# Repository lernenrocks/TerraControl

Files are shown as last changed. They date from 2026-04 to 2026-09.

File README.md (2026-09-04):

# TerraControl

> **🚧 Currently being redesigned.** Sensor and relay handling are being
> reworked onto a shared class hierarchy (NVI pattern), and the project
> went headless (no display, no SD card) in favor of a web GUI. This
> README does not reflect the current architecture yet — it will be
> updated once the redesign settles.

*Smart terrarium control for those who don't want their setup 
to stop working the day some company decides to shut down their 
servers — and for those who need more than one or two plugs. 
A work in progress measured in years, not sprints, with a parts budget that long surpassed the 
price of the off-the-shelf box, not counting the ones that 
released their magic smoke. And if this accidentally turns out 
to be a solid foundation for a home automation system — well, 
that was definitely not the plan.*

## How It Works

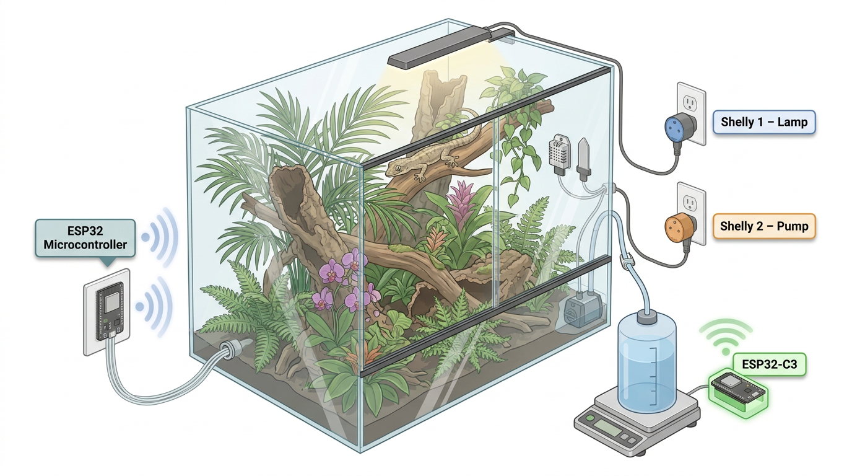
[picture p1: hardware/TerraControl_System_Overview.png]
TerraControl System Overview


> **Note:** The system overview image is AI-generated (FigureLabs).
> It contains minor technical inaccuracies that survived several
> rounds of prompt engineering before patience and token budget
> ran out simultaneously. It will be replaced by actual photos
> once the prototype is running. If you happen to have a free and
> freely usable image of a terrarium control setup — contributions
> are very welcome.
>
> **Not current** — this image predates the headless decision and
> the sensor/relay redesign; some details no longer match the actual
> architecture.

An ESP32 sits at the heart of the system as the **MainUnit**. It runs its own WiFi access point — Shelly smart plugs connect directly to the ESP32, not to your home router. This keeps all device communication local and independent of cloud services or internet connectivity.

Sensors measure conditions inside the terrarium (temperature, humidity, soil moisture). The MainUnit reads these values and switches the Shellys accordingly — controlling lighting, heating, irrigation, or anything else that plugs into a wall socket.

The ESP32 also connects to your home router as a client, exclusively for time synchronization and future remote access. If your router goes down, the Shellys and sensors remain fully operational.

**Shelly smart plugs** are identified by their MAC address, not by IP. The ESP32 assigns and tracks IPs automatically — no manual configuration required on the network side.

## Roadmap

- [x] Shelly Gen2/3 control — switch on/off, status monitoring, authenticated via SHA-256 Digest Auth
- [x] Soft-AP — ESP32 as primary access point; Shellys connect directly to ESP32, isolated from the home network
- [x] WiFiWorker — dedicated background task handling all network communication with Shellys (being split into RequestWorker + GuiWorker)
- [x] `SensorBase` (NVI pattern) — DHT22 temperature/humidity (4 local) and capacitive soil moisture (1 local) rebuilt on a shared, NVS-backed sensor abstraction
- [ ] `RelayBase` (NVI pattern) — Shelly relays on the same abstraction as sensors, with optional LED indicator / power metering capabilities
- [ ] Remote sensors — ESP32-C3 nodes outside the terrarium, polled on demand
- [ ] RTC (DS3231) + local SNTP server — timekeeping independent of the home router
- [ ] Switching logic — connect a sensor value to a Shelly, with threshold and time-based rules
- [ ] JSON config layer — serialization/deserialization for all settings
- [ ] NOR flash logging — external SPI flash for log storage (replaces the originally planned SD card)
- [ ] NVS — persist last valid configuration across reboots
- [ ] Onboarding wizard — zero-config binding of new Shellys and sensors from factory reset

The project went headless — no display, no SD card slot, both removed from the hardware. The web GUI (proven out on a companion ESP32-C3 sensor-node project) turned out flexible enough to be the sole interface.

## Hardware

### MainUnit v1 (current)

| Component | Description | Quantity |
|---|---|---|
| ESP32 DevKit V1 | ESP32-WROOM-32D, 38-pin | 1 |
| Shelly Plug S | Smart Wi-Fi power plug, Gen2/3 | 1–8 |
| DHT22 | Temperature and humidity sensor | up to 4 |
| Soil Moisture Sensor V1.2 | Capacitive, corrosion-resistant | 1 |
| MB102 | Breadboard power supply 3.3V / 5V | 1 |
| S8050 | NPN transistor, TO-92 (display backlight) | 1 |
| Resistor | 1kΩ | 1 |
| Capacitor | 100nF ceramic (104) | 1 |
| Capacitor | 100µF electrolytic | 2 |
| Breadboard | 830 holes | 2–3 |
| Dupont cables | Male-to-Male / Male-to-Female / Female-to-Female | assorted |
| USB cable | Micro-USB, for ESP32 power and flashing | 1 |
| Power supply | 9–12V DC barrel jack, min. 1A | 1 |
| Coffee | Black, strong | ∞ |

### Planned / Optional

| Component | Description | Purpose |
|---|---|---|
| ESP32-C3 Super Mini | Remote sensor node | Sensors outside the terrarium, connected via WiFi |
| TFT Display | 3.2" SPI ILI9341 / XPT2046 Touch / SD-Card slot | On-device configuration and monitoring |
| DS3231 RTC | I²C Real Time Clock with battery backup | Timekeeping independent of NTP |
| LIR2032 | Rechargeable backup battery | DS3231 backup power |

The following diagram shows the wiring of the MainUnit v1 prototype.
Depending on the components used, wiring may differ —
particularly for the display module, as variations in pinout
and layout are common across manufacturers.

The wiring diagram and the hardware list may contain errors.

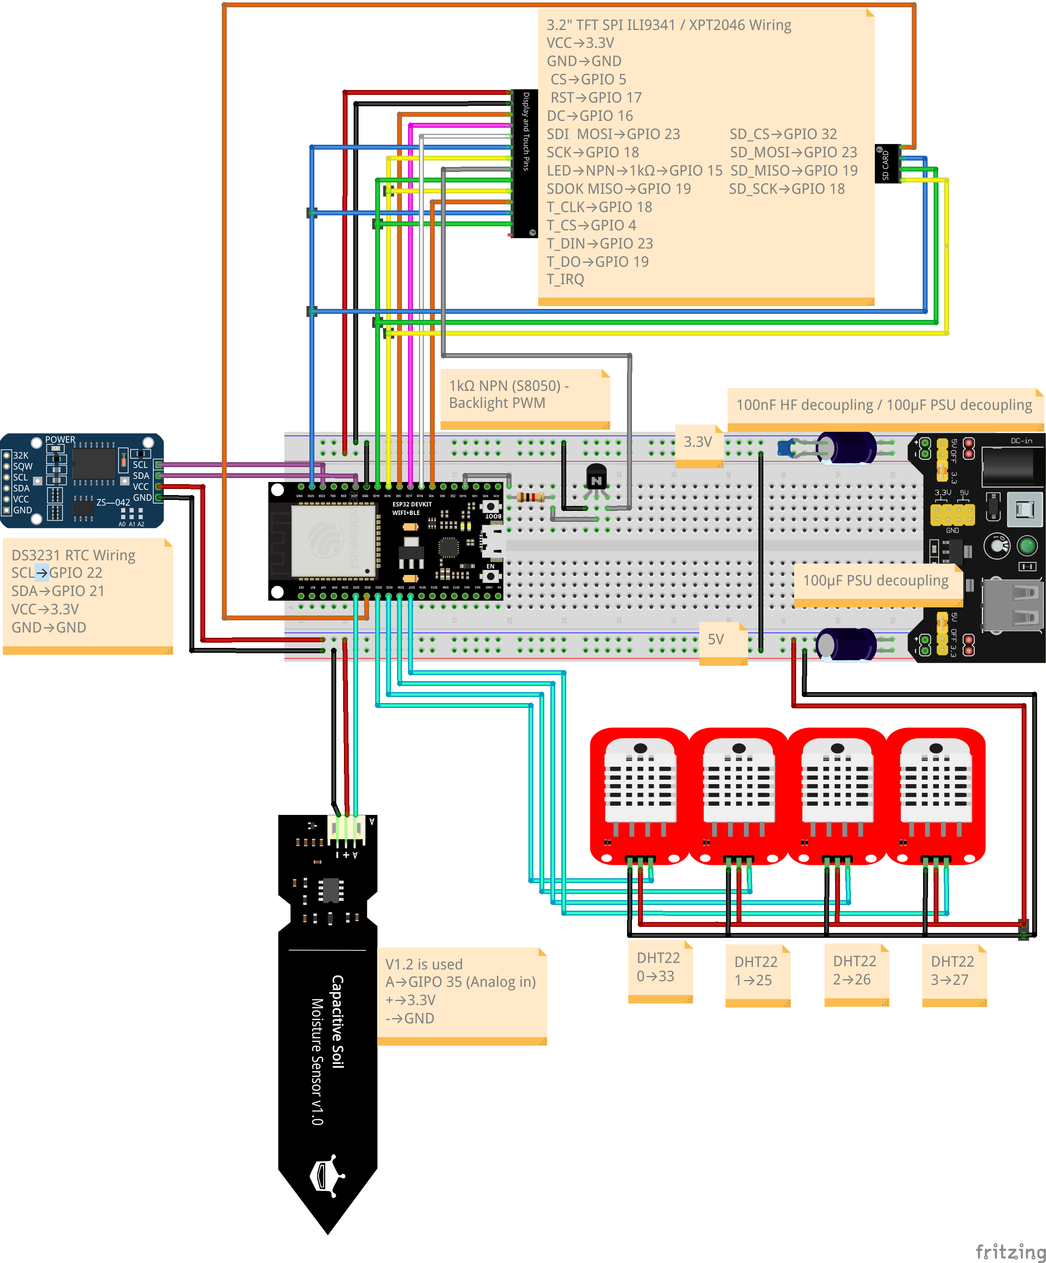
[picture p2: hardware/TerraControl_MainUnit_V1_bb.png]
TerraControl MainUnit v1


*[Download full diagram (PDF)](hardware/TerraControl_MainUnit_V1_bb.pdf)*

> **Not current** — predates the headless decision (no display, no SD card).

## Getting Started

### Prerequisites
- [VS Code](https://code.visualstudio.com/) with the [PlatformIO](https://platformio.org/) extension
- ESP32 DevKit V1 (ESP32-WROOM-32D) and the hardware described above
- One or more Shelly Gen2/3 smart plugs (Plug S recommended)

### Installation

1. Clone the repository
```bash
git clone https://github.com/lernenrocks/TerraControl.git
```

2. Copy the WiFi configuration template and fill in your credentials
```bash
cp include/wifi_config.h.example include/wifi_config.h
```

3. Open the project in VS Code with PlatformIO and flash it to your ESP32

4. Power on your Shelly plugs. In the Shelly app or web interface, connect each Shelly to the ESP32's access point:
   - SSID: the device name configured in `wifi_config.h` (default: `TerraControl`)
   - Password: `AP_WIFI_PW` from `wifi_config.h`
   
   Once connected, the ESP32 identifies each Shelly by its MAC address and begins monitoring and controlling it automatically.

### Libraries
The following libraries are required and will be installed automatically by PlatformIO:
- `northernwidget/DS3231`
- `bodmer/TFT_eSPI`
- `adafruit/DHT sensor library`
- `bblanchon/ArduinoJson`

> **Note:** Library versions may change as development progresses,
> particularly if LVGL is adopted for the display interface.

## AI Assistance

This project is developed with support from [Claude Code](https://claude.ai/code) (Anthropic). Claude assists with firmware architecture decisions, code reviews, writing and refining unit tests, and keeping the codebase consistent with the project's strict constraints, e.g. no heap allocation, no `HTTPClient`, direct `WiFiClient` usage throughout.

The architectural rules and conventions are maintained in `CLAUDE.md`, which serves as the authoritative reference for the collaboration. Claude works within those boundaries rather than around them.

## Feedback
Questions and feedback are always welcome — feel free to open an issue.
Please note that this is a hobby project and response times may vary.

## Author
Andy / lernenrocks<br>
[www.lernen.rocks](https://lernen.rocks/)

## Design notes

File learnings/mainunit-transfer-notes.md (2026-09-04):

# Übertragbarkeit RemoteSensor → MainUnit

Zusammenfassung der Konventionen und Learnings aus diesem Projekt, gruppiert danach, wie direkt sie auf die MainUnit übertragbar sind. Bug-Muster im Detail: [stille-bugs.md](stille-bugs.md).

---

## A. Firmware-Konventionen (allgemein, wahrscheinlich 1:1 übertragbar)

- **Heap-Disziplin**: kein `String`/`malloc`/`DynamicJsonDocument`, stattdessen `char[]` + `snprintf`/`strlcpy`, `StaticJsonDocument`. `new` nur für Objekte, die die gesamte Laufzeit leben (keine zyklische Allokation).
- **RAII statt manueller Paarung** für alles, was zwingend zusammen auf-/abgebaut werden muss (`InternalStorage::Session` als Vorlage für NVS-Zugriffe) — verhindert vergessenes `end()` in Fehlerpfaden.
- **NVI-Pattern** für Geräte-/Sensorabstraktionen (`SensorBase`: `read()` public non-virtual, `isValid()`/`readRaw()` private pure virtual) — falls die MainUnit eine eigene Aktor-/Sensor-Abstraktion braucht, gleiches Muster sinnvoll.
- **Modultrennung nach Abhängigkeit, nicht nach Thema** — `DigestCrypto`/`DigestHeaderParser`/`DigestAuth`/`System`/`JsonEscape` sind getrennt, weil sie unterschiedliche Abhängigkeiten haben (mbedtls/WiFi/NVS/nichts), nicht weil's "anders klingende" Module sind. Kriterium fürs Aufteilen: eine Datei braucht eine Abhängigkeit, die eine andere nicht braucht.
- **Keine verfrühte Abstraktion** — Gemeinsamkeiten erst hochziehen, wenn ein zweites echtes Beispiel existiert (Beispiel `HX711Sensor::_pId`, bewusst nicht auf `SensorBase` verallgemeinert).
- **Gekoppelte Puffergrößen aus einer gemeinsamen Konstante ableiten**, nie zwei unabhängige Zahlen für dieselben Daten pflegen (Cheatsheet #4).
- **Truncation vs. Ablehnung**: Längen-Validierung *vor* dem Schreiben, ablehnen statt hinterher still kürzen (Cheatsheet #1) — gilt für jedes Freitextfeld (Namen, Passwörter, o. ä.).
- **Wortgrenzen-Prüfung bei String-Suche**, wenn ein Feldname Präfix/Suffix eines anderen sein kann (Cheatsheet #2, der `nonce`/`cnonce`-Bug) — relevant für jeden handgeschriebenen Parser.
- **Exaktes Routing** (`strcmp` auf schon geparstem Pfad) statt `strstr`-Präfixmatch auf dem Rohheader (Cheatsheet #3) — direkt relevant, falls die MainUnit einen eigenen HTTP-Server fährt.
- **`DEBUG_LOG(...)`-Makro** statt verstreuter `#ifdef`/`Serial.printf`/`#endif`-Blöcke — Makro, nicht Funktion, damit im Release-Build wirklich nichts übrig bleibt.
- **Ein Handler pro Route**, als eigene benannte Funktion — hält `handle()` kurz, unabhängig von der Zahl der Endpoints.
- **Digest Auth (SHA-256), MAC im Realm** — falls die MainUnit ihre eigene GUI jetzt auch schützen will (siehe unten, headless-Entscheidung), ist das hier komplett fertige, hardwaregetestete Referenzimplementierung, kein Neuentwurf nötig.

## B. GUI-Konventionen (JS/HTML — direkt relevant, da die MainUnit jetzt auch web-GUI-first wird)

- **Datengetrieben rendern** — GUI baut sich aus einer JSON-Response (`/calibrationinfo`) auf, kein hardcodiertes Wissen über Sensortypen/Anzahl im JS.
- **Kleinstmögliche Neu-Render-Fläche**: nicht die ganze Karte/Seite neu aufbauen, wenn nur ein Feld sich ändert — eigener State-Container pro unabhängig bearbeitbarem Feld (Lehre aus dem Name/Offset-Interferenz-Bug von heute Abend: ein Toggle hat ein anderes, gerade offenes Feld überschrieben, weil beide aus demselben vollständigen Re-Render kamen).
- **Neutrale Platzhalter statt falscher Default-Werte** — leer/`…` statt eines konkreten (kurzzeitig falschen) Namens, sonst "zuckt" die Anzeige beim Laden.
- **`document.title` und Favicon live aktualisieren** — beides unproblematisch per JS setzbar, kein Grund, das auszulassen.
- **Digest Auth im Browser läuft transparent** — kein JS-seitiger Nachbau möglich/nötig, Browser zeigt eigenen Login-Dialog, Zugangsdaten werden pro Origin automatisch mitgeschickt.
- **Für Weg 2 (embed_txtfiles) nicht mehr nötig**: die "Extended Embedded Languages"-VSCode-Extension, die hier für Syntax-Highlighting in `R"html(...)html"`-Strings genutzt wurde — bei echten `.css`/`.js`-Dateien via `embed_txtfiles` gibt's das Problem gar nicht erst.

## C. Test-/Verifikations-Workflow (Technik, nicht Konvention — aber praktisch bewährt)

- **Headless Firefox + gemockter `fetch()`** zum Testen der GUI ohne Hardware — mehrfach heute genutzt (Syntax-Check, Funktionsscreenshots, Interferenz-Bug reproduziert). Kein Node.js in dieser Umgebung verfügbar, Firefox war der verlässliche Ersatz.
- **`window.onerror`-Marker-Trick** für JS-Syntax-Checks ohne echten Parser/Node — eine Zeile am Ende desselben `<script>`-Blocks, die nur läuft, wenn alles davor sauber geparst hat.
- **PlatformIO `[env:native]` + `default_envs`** — reine Logik-Module (keine WiFi-/NVS-Abhängigkeit) hostnativ testbar, ohne dass `pio run`/IDE-Buttons den Test-Env aus Versehen mitziehen.

## D. MainUnit-spezifische Entscheidungen aus dem heutigen Gespräch (keine C3-Konvention, sondern schon MainUnit-Planung)

- **Headless-Entscheidung**: MainUnit bekommt kein Display mehr — die hier entwickelte Web-GUI hat sich als flexibel/brauchbar genug erwiesen, um die primäre Oberfläche zu sein. Spart auch Flash-Platz (keine Display-GUI-Lib).
- **HTML/CSS/JS-Einbettung**: bewusst Weg 2 (`board_build.embed_txtfiles`, echte Dateien) statt der hier genutzten Raw-String-Technik — mehr Tooling, dafür etwas mehr Umstellungsaufwand (`client.write(start, end-start)` statt `client.print()`, da nicht automatisch nullterminiert).
- **Log-Speicher**: externer SPI-NOR-Flash (W25Q-Familie), nicht NAND — bei ca. 5–10 MB/Jahr (10-Minuten-Intervall, Sensorwerte + Schaltzustände) ist NAND weder günstiger (echte Marktpreise: ~9–11 USD für 1-Gbit-SPI-NAND bei LCSC, ab 38 Stück) noch nötig, dafür aber komplexer (Bad-Block-Management, ECC, LittleFS hat keine ausgereifte NAND-Unterstützung). Bis 16 MB (128 Mbit) keine Adressierungs-Sonderfälle, darüber (32 MB+) braucht's 4-Byte-Adressierung — vorher prüfen, ob die genutzte Lib das unterstützt.
- **Mehrere NOR-Chips statt einem großen**: separate Chip-Select-Leitung pro Chip am selben SPI-Bus (MOSI/MISO/SCK geteilt) — günstiger und einfacher als ein einzelner großer/teurerer Chip. Zwei Wege, das Software-seitig zu nutzen: vereinheitlichte Block-Device-Schicht für LittleFS, oder (einfacher, passend zum Append-only-Log) einfach umschalten, welcher Chip gerade aktiv beschrieben wird.
- **Log-Rotation**: monatlich statt täglich (aktuelle SD-Praxis) — bei mehrjähriger Aufbewahrung deutlich weniger Dateien für die GUI-Liste (12/Jahr statt 365/Jahr).
- **Retention-Policy**: automatische FIFO-Rotation (ältester Monat wird gelöscht, wenn Platz für einen neuen gebraucht wird) als Sicherheitsnetz, GUI-Download+manuelles Löschen zusätzlich für gezieltes Archivieren — nicht rein manuell, sonst braucht's Nutzerpflege, damit das Gerät nicht "volläuft".

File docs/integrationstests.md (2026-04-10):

# Integration Tests — TerraControl

To be performed manually before every merge to `main`.  
Test setup: 3 Shelly Gen2/3 devices with hardcoded MACs, ESP32 in local network.

---

## Checklist

### 1. mDNS Discovery

**Precondition:** All 3 Shellys plugged in and connected to WiFi.

- [x] Start ESP32 — All 3 Shellys found via mDNS and registered in DataHub
- [x] Check Serial log — No `[ERROR]` during discovery

---

### 2. MAC Verification

**Precondition:** One Shelly with unknown MAC in the network (e.g. temporarily add a foreign Shelly).

- [x] ESP32 attempts to contact unknown Shelly — MAC check fails, device is not added to DataHub
- [x] Check Serial log — device shows as `OFFLINE / never seen`, not switched

---

### 3. Switching

**Precondition:** All 3 Shellys found via mDNS, `online == true`.

- [x] Switch relay on (`turn=on`) — Shelly switches on, `getStatus()` confirms `output == true`
- [x] Switch relay off (`turn=off`) — Shelly switches off, `getStatus()` confirms `output == false`
- [x] Switch all 3 Shellys in sequence — No connection errors, all respond with HTTP 200

---

### 4. Stability Test

**Precondition:** Normal operation, all Shellys online.

- [x] Run ESP32 for >5 minutes — No crash, no watchdog reset (tested 3h)
- [x] Check Serial log after 5 minutes — No unexpected `[ERROR]`
- [x] Compare `[HEAP]` entries in Serial log — Free heap remains stable — no continuous decline

---

## Not yet tested (deliberately omitted)

**Offline/Online cycle** (unplugging and replugging a Shelly) — will be documented once the user-facing Shelly management is stable.

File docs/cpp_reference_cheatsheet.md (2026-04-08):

# C++ Parameter- / Objekt-Access Cheatsheet

## 1) Call-by-Value vs Call-by-Reference vs Pointer

### Call-by-Value
`void f(WiFiStatus x)`
- beim Aufruf wird `x` kopiert (tief für Plain-Old-Data)
- Änderungen in `f` wirken nicht auf den Caller
- TTL: läuft im Scope von `f`

### Call-by-Reference
`void f(WiFiStatus &x)`
- `x` ist Alias auf Originalobjekt
- Änderungen wirken im Aufrufer sichtbar
- `x` kann nicht null sein

### Call-by-Pointer
`void f(WiFiStatus *x)`
- `x` ist Adresse (`nullptr` möglich)
- Zugriff via `x->...`
- ggf. `if(!x) return;`

## 2) Struct member assignment vs Copy

```cpp
WiFiStatus a, b;
a = b; // Werte von b in a kopieren (für POD memberwise)
```

- kein Call-by-Value hier, sondern Zuweisung (assignment)!
- Bools, int etc. werden Feld-für-Feld kopiert

## 3) Getter/Setter mit Lock im DataHub

```cpp
bool getWiFiStatus(WiFiStatus &out) {
    if (xSemaphoreTake(dataHubMutex,pdMS_TO_TICKS(100)) != pdTRUE) return false;
    out = dataHub.wifiStatus;  // Kopie in Referenz-Objekt
    xSemaphoreGive(dataHubMutex);
    return true;
}

bool updateWiFiStatus(const WiFiStatus &in) {
    if (xSemaphoreTake(dataHubMutex,pdMS_TO_TICKS(100)) != pdTRUE) return false;
    dataHub.wifiStatus = in;   // deep copy
    xSemaphoreGive(dataHubMutex);
    return true;
}
```

## 4) DTO / RelayUpdate Pattern (Bulk-Update)

```cpp
struct RelayUpdate {
    char mac[MAC_LEN];
    int id;
    bool output;
    bool hasOutput;
    float temperature;
    bool hasTemperature;
    // ...
};

bool applyRelayUpdate(const RelayUpdate &u) {
    if (xSemaphoreTake(dataHubMutex,pdMS_TO_TICKS(100)) != pdTRUE) return false;
    WifiRelay *r = findWifiRelay("mac", u.mac, u.id);
    if (!r) { xSemaphoreGive(dataHubMutex); return false; }
    if (u.hasOutput) r->output = u.output;
    if (u.hasTemperature) r->temperature = u.temperature;
    xSemaphoreGive(dataHubMutex);
    return true;
}
```

- Vorteil: neue Felder können kontrolliert ergänzt werden
- Verhindert zudem wilde API-Explosion

## 5) FreeRTOS Lock-Timeout

`xSemaphoreTake(dataHubMutex, pdMS_TO_TICKS(100))`
- `pdTRUE` = Lock erhalten
- `pdFALSE` = Timeout (hier 100ms)
- `portMAX_DELAY` = unbegrenzt warten (nicht für UI empfohlen)

## 6) Pointer vs Referenz Key-Differenzen
- Referenz: muss gebunden sein, kann nicht null, kein Rebind
- Pointer: kann null, kann auf anderes Objekt zeigen, pointer arithmetic möglich

## 7) Empfehlung
- Kapsle Daten in API (`get*/set*` / `apply*`)
- Vermeide externen direkten `dataHub.wifiRelay[i]`-Zugriff
- Nutze defaults im Struct (z.B. `Status=UNKNOWN`)
- C++ ist nicht Java: Verhalten (Kopie vs Ref) muss immer explizit sein

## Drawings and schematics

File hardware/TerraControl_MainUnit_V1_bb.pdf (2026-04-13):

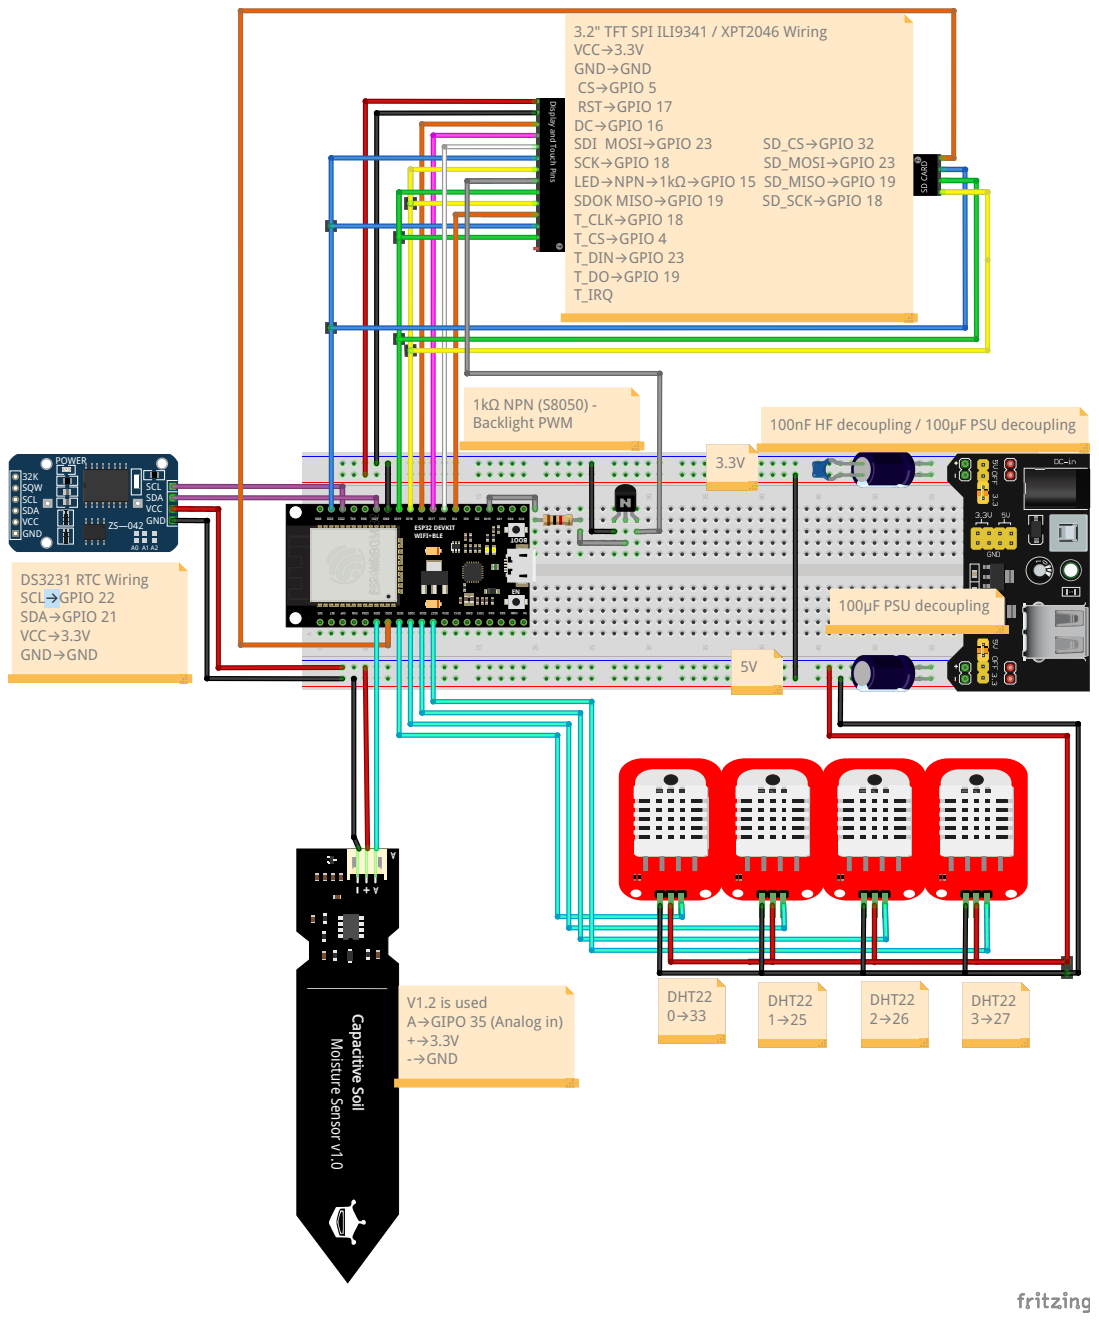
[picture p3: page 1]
GND; TXD; RXD; SCK; ESP32 DEVKIT WIFI+BLE; POWER; 32K SQW SCL SDA VCC GND; SCL SDA VCC GND; Capacitive Soil; Moisture Sensor v1.0; DHT22 3→27; DHT22 2→26; DHT22 1→25; DHT22 0→33; DS3231 RTC Wiring L→G SDA→GPIO 21 VCC→3.3V GND→GND; 100µF PSU decoupling; 1kΩ NPN (S8050) - Backlight PWM; SDI MOSI→GPIO 23; SD_CS→GPIO 32; SCK→GPIO 18; SD_MOSI→GPIO 23; SDOK MISO→GPIO 19; SD_SCK→GPIO 18

3.2" TFT SPI ILI9341 / XPT2046 Wiring
VCC→3.3V
GND→GND
CS→GPIO 5
RST→GPIO 17
DC→GPIO 16
LED→NPN→1kΩ→GPIO 15 SD_MISO→GPIO 19
T_CLK→GPIO 18
T_CS→GPIO 4
T_DIN→GPIO 23
T_DO→GPIO 19
T_IRQ

Display and Touch Pins

100nF HF decoupling / 100µF PSU decoupling

V1.2 is used
A→GIPO 35 (Analog in)
-→GND

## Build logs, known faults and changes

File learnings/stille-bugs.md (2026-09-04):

# Stille Bugs

Acht wiederkehrende Fehlermuster, gefunden im Firmware-Review des ESP32-C3 RemoteSensor — zum Wiedererkennen in künftigen Projekten.

Jeder Punkt hier hat im Review real etwas kaputt gemacht oder wäre fast unbemerkt geblieben — keiner davon hat beim Kompilieren angeschlagen. Das ist auch der rote Faden: **alle acht Muster versagen still**, nicht laut. Sie fallen nicht durch eine Fehlermeldung auf, sondern durch ein falsches Ergebnis, eine veraltete Doku oder einen Bug, der sich erst mit der zweiten Instanz zeigt.

*Projekt: RemoteSensor / TerraControl · Quelle: 6 Review-Themen (Security, Korrektheit, Puffergrößen, Doku-Abgleich, Fehlerbehandlung, Tests) · Stand: 2026-08-23*

---

## 01 · Puffer — Kürzen statt ablehnen

**Regel:** Wenn eine Länge eine harte Grenze hat: explizit prüfen und mit Fehler ablehnen — nicht stillschweigend kürzen und weitermachen.

**Warum:** Eine zu lange Eingabe wird beim nächsten Lesen unbemerkt gekürzt. Der User merkt nichts — das System verhält sich dauerhaft anders als das, was er eingegeben hat.

**Beispiel aus dem Projekt:** `DigestCrypto::computeHa1()`s internes `input[128]` kürzte lange Passwörter (>~92 Zeichen) still — der Hash wurde aus einem kürzeren Passwort berechnet, ohne Fehler. Fix: `MAX_PASSWORD_LEN=63` serverseitig geprüft, dieselbe Lücke danach auch bei `POST /provision/name` gefunden und geschlossen.

---

## 02 · Parsing — Teilstring-Match ohne Wortgrenze

**Regel:** Bei Suche nach einem Feldnamen oder Pfad nie nur eine reine Teilstring-Suche nutzen, wenn ein Name Präfix oder Suffix eines anderen sein kann.

**Warum:** `strstr` findet den ersten Treffer — unabhängig davon, ob er zufällig innerhalb eines längeren Wortes liegt. Ohne Grenzprüfung ist das Ergebnis vom Zufall der Zeichenkette abhängig.

**Beispiel aus dem Projekt:** Die Suche nach `"nonce="` fand denselben Text versehentlich innerhalb von `"cnonce=..."` — falsches Feld extrahiert, sobald `cnonce` vor `nonce` im Header steht (laut RFC 7616 erlaubt). Ein Unit-Test deckte es auf; Fix per Wortgrenzen-Check.

```cpp
// vorher: erster Treffer gewinnt, egal wo er sitzt
strstr(line, "nonce=\"")        // trifft auch in "cnonce=..."

// nachher: nur ein Treffer an einer echten Feldgrenze zählt
findFieldStart(line, "nonce=\""); // prüft: Zeichen davor alphanumerisch? -> weitersuchen
```

---

## 03 · Routing — Präfix- statt Exact-Match

**Regel:** Routen/Kommandos exakt vergleichen, nicht per Teilstring-Suche auf dem Rohtext — sonst matcht ein längerer, unbeabsichtigter Pfad mit.

**Warum:** Ein Tippfehler oder eine falsche Erweiterung im Client wird nicht als Fehler sichtbar, sondern führt zufällig zu einer echten Antwort — die Route "funktioniert" für Anfragen, die sie eigentlich nie hätte akzeptieren dürfen.

**Beispiel aus dem Projekt:** `strstr(header, "GET /status")` matchte auch `GET /statusXYZ` mit `200 OK` statt `404`. Fix: `strcmp` auf dem bereits exakt geparsten Pfad statt Teilstring-Suche im rohen Request-Header.

---

## 04 · Puffer — Zwei Zahlen, die eigentlich eine sein sollten

**Regel:** Wenn zwei Puffer aus denselben Daten befüllt werden, ihre Größe aus *einer* gemeinsamen Konstante ableiten — nicht zwei unabhängige Zahlen parallel pflegen.

**Warum:** Ändert sich eine Grenze, aber die zweite, eigentlich abhängige Stelle bleibt unverändert, entsteht eine stille Kürzung an einer ganz anderen Stelle im Code — ohne offensichtlichen Zusammenhang zur eigentlichen Änderung.

**Beispiel aus dem Projekt:** `HA2_INPUT_BUF_LEN` wurde ursprünglich aus einer eigenen, unabhängigen `URI_BUF_LEN` berechnet — statt aus `DigestAuth::MAX_URI_LEN`, dem Wert, der tatsächlich für den `path`-Puffer in `HttpServer.cpp` galt.

---

## 05 · RAII — Manuelles Pairing statt automatischer Freigabe

**Regel:** Wenn zwei Aufrufe immer zusammen auftreten müssen (`begin()`/`end()`, Lock/Unlock …), in einen RAII-Wrapper packen — nicht auf Disziplin an jeder einzelnen Call-Site verlassen.

**Warum:** Ein vergessenes `end()`, etwa bei einem frühen `return` in einem Fehlerpfad, hält eine Ressource offen. Das passiert nur in Randfällen und ist im Alltagstest kaum zu sehen.

**Beispiel aus dem Projekt:** `InternalStorage::begin()/end()` wurden an rund einem Dutzend Stellen manuell gepaart. Fix: `InternalStorage::Session` — der Destruktor ruft `end()` garantiert auf, auch bei vorzeitigem Funktionsende.

---

## 06 · State — Geteilter Puffer für Instanz-eigene Daten

**Regel:** Ein Wert, der sich pro Objekt-Instanz unterscheiden muss, gehört als Member in die Instanz — nicht in einen globalen oder statisch geteilten Puffer.

**Warum:** Mit nur einer Instanz fällt der Bug nie auf. Er entsteht erst, sobald eine zweite Instanz denselben geteilten Puffer überschreibt — typischerweise genau dann, wenn das Projekt wächst.

**Beispiel aus dem Projekt:** `HX711Sensor` cachte den NVS-Namespace früher in einem globalen `char[12]`. Mit zwei HX711-Sensoren hätte der zweite die Kalibrierdaten des ersten gelesen und überschrieben. Fix: `_pId` als privates Member, Namespace wird bei jedem Zugriff frisch aus der Instanz gebaut.

---

## 07 · Doku — Doku driftet lautlos vom Code weg

**Regel:** Nach jeder Erweiterung einer Response, eines Interfaces oder eines öffentlichen Members die Doku im selben Schritt mitziehen — nicht als separaten, später nachgeholten Durchgang.

**Warum:** Doku, die man beim Programmieren nicht mehr anschaut, verrottet unbemerkt. Monate später vertraut man ihr trotzdem wieder blind — sie sieht ja vollständig aus.

**Beispiel aus dem Projekt:** `GET /status` bekam im Lauf der Feature-Arbeit vier neue Felder (`device_name`, `ssid`, `provisioned`, `password_set`) — das dokumentierte JSON-Beispiel blieb auf dem alten Stand, bis der explizite Doku-Abgleich es aufdeckte.

---

## 08 · Testbarkeit — Reine Logik hinter Hardware-Code versteckt

**Regel:** Logik ohne Hardware-/Netzwerkzugriff früh von hardwaregekoppeltem Code trennen — auch wenn es anfangs bequemer ist, sie einfach in derselben Datei mitlaufen zu lassen.

**Warum:** Ohne diese Trennung lässt sich die Logik nie isoliert testen. Und genau dort verstecken sich oft die unauffälligsten Bugs — siehe Punkt 02, der ohne diese Trennung nie einen Test bekommen hätte.

**Beispiel aus dem Projekt:** `escapeJsonString`/`extractValue` mussten aus `HttpServer.cpp`/`DigestAuth.cpp` in eigene, abhängigkeitsfreie Module (`JsonEscape`, `DigestHeaderParser`) verschoben werden, um sie nativ — ohne Board — zu testen.

---

*Zusammengestellt aus dem Code-Review des ESP32-C3-RemoteSensor-Projekts.*

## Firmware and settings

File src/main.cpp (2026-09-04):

/*
 * WiFiManager Test - Minimal Setup
 * Zweiter ESP32 ohne angeschlossene Hardware
 * Komplett clean - nur WiFiManager
 */

#include <Arduino.h>
#include <Preferences.h>
#include <esp_system.h>
#include "wifi_config.h"
#include "WiFiManager.h"
#include "WiFiWorker.h"
#include "DataHub.h"
#include "SensorManager.h"
#include "SoilMoisture.h"
#include "SensorTypes.h" // @note remove if loading from JSON is implemented
#include "Controller.h"
#include "NvsStorage.h"

#define APP_VERSION "0.1"

void setup()
{
  Serial.begin(115200);
  delay(2000); // Zeit zum Öffnen des Serial Monitors

  /** @note Boot Counter für Debugging */
  /*
  Preferences prefs;
  prefs.begin("system", false);
  uint32_t bootCount = prefs.getUInt("bootCount", 0);
  bootCount++;
  prefs.putUInt("bootCount", bootCount);
  prefs.end();
*/
  // esp_reset_reason_t rr = esp_reset_reason();
  // Serial.printf("\n=== BOOT START === (#%u, reset=%d)\n", bootCount, (int)rr);
  Serial.printf("Version: %s\n", APP_VERSION);
  Serial.printf("Freier Heap: %u Bytes\n", ESP.getFreeHeap());
  NvsStorage::init();

  // FIXME old:
  Serial.println("\n--- Setup abgeschlossen ---");
  Serial.println("Bereit für WiFiManager Neuaufbau\n");
  /*
  DataHub::initDataHub();

  DataHub::WifiRelay relay = {};
  relay.inUse = true;
  relay.id = 0;
  relay.relayMode = RelayTypes::RelayMode::FORCED_OFF;
  relay.switchDuration = 60000;
  strncpy(relay.mac, TERRA_CONTOL_000_MAC_STR, sizeof(relay.mac) - 1);
  DataHub::setWifiRelayEntry(relay, 0);
  relay = {};
  relay.inUse = true;
  relay.id = 0;
  relay.relayMode = RelayTypes::RelayMode::FORCED_OFF;
  relay.switchDuration = 60000;
  strncpy(relay.mac, TERRA_CONTOL_001_MAC_STR, sizeof(relay.mac) - 1);
  DataHub::setWifiRelayEntry(relay, 1);
  relay = {};
  relay.inUse = true;
  relay.id = 0;
  relay.relayMode = RelayTypes::RelayMode::FORCED_OFF;
  relay.switchDuration = 60000;
  strncpy(relay.mac, TERRA_CONTOL_002_MAC_STR, sizeof(relay.mac) - 1);
  DataHub::setWifiRelayEntry(relay, 2);

  WiFiManager::initWiFi();
  WiFiManager::updateWifiStatus();
  // DataHub::dataHubToSerial();
  //? Sensoren anmelden und Testen
*/
  if (!SensorManager::init())
  {
    Serial.println("nicht alle Sensoren initialisiert, Logs prüfen");
  }
  else
    Serial.println("Sensoren initialisiert");

  // Testaufruf: Kalibrierungs-JSON-Pfad für den Bodenfeuchtesensor durchspielen.
  // idx=8 gilt nur für den heutigen Boot (alle 8 DHT-Allokationen erfolgreich, Soil Moisture als 9. Sensor) - kein stabiler Wert.
  StaticJsonDocument<64> calDoc;
  calDoc[CALIBRATE_KEY_DRY] = 3080.0f;
  calDoc[CALIBRATE_KEY_WET] = 1220.0f;
  if (SensorManager::calibrateSensorHardware(calDoc.as<JsonObjectConst>(), 8))
    Serial.println("Soil Moisture kalibriert");
  else
    Serial.println("Soil Moisture Kalibrierung fehlgeschlagen");

  Serial.println("--- Sensor-Konfiguration ---");
  SensorManager::printSensorConfigsToSerial();

  Serial.println("Setup beendet.");
}

void loop()
{
  unsigned long now = millis();
// Controller::update(now);

  static unsigned long lastSensorPrint = 0;
  if (now - lastSensorPrint >= 5000)
  {
    lastSensorPrint = now;
    SensorManager::printSensorsToSerial();
  }
}

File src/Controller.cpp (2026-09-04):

#include "freertos/FreeRTOS.h"
#include "Controller.h"
#include "DataHub.h"
#include "WiFiWorker.h"
#include "WiFiWorkerTypes.h"
#include "SensorManager.h"
#include <Arduino.h>

#define CONTROLLER_UPDATE_INTERVAL 200UL
#define SWITCH_RETRY_INTERVAL_MS 2000UL

namespace
{
    DataHub::DataHub dataHub = {};
    unsigned long lastSwitchOn[RELAY_SIZE] = {};
    unsigned long lastStatusRequest[RELAY_SIZE] = {};
    /**
     * @brief monitors the status of all wifiRelays
     * @param now current timestamp in millis
     *
     */
    void monitorRelayStatus(unsigned long now)
    {
        for (size_t i = 0; i < RELAY_SIZE; i++)
        {
            DataHub::WifiRelay &relay = dataHub.wifiRelay[i];
            if (!relay.inUse)
            {
                continue;
            }
            if (relay.ipV4Adress[0] == '\0' || strcmp(relay.ipV4Adress, "0.0.0.0") == 0)
            {
                continue;
            }
            if (now - lastStatusRequest[i] > dataHub.systemData.relayStatusInterval_ms)
            {
               // Serial.printf("[CTRL] Relay[%d] %s → GET_STATUS\n", i, relay.name);
                lastStatusRequest[i] = now;
                WiFiWorker::queueRelayCommand(i, WiFiWorker::RelayCommand::GET_STATUS);
            }
        }
    }
    /**
     * @brief switches a relay into the desired Mode
     * @param now the current timestap in millis
     */
    void enforceRelayState(unsigned long now)
    {
        for (size_t i = 0; i < RELAY_SIZE; i++)
        {
            DataHub::WifiRelay &relay = dataHub.wifiRelay[i];
            if (!relay.online)
            {
                continue;
            }
            switch (relay.relayMode)
            {
            case RelayTypes::RelayMode::FORCED_ON:
                if (now - lastSwitchOn[i] > relay.switchDuration / 3 ||
                    (!relay.output && now - lastSwitchOn[i] > SWITCH_RETRY_INTERVAL_MS))
                {
                   // Serial.printf("[CTRL] Relay[%d] %s → SWITCH_ON\n", i, relay.name);
                    lastSwitchOn[i] = now;
                    WiFiWorker::queueRelayCommand(i, WiFiWorker::RelayCommand::SWITCH_ON);
                }
                break;
            case RelayTypes::RelayMode::FORCED_OFF:
                if (relay.output)
                {
                   // Serial.printf("[CTRL] Relay[%d] %s → SWITCH_OFF\n", i, relay.name);
                    WiFiWorker::queueRelayCommand(i, WiFiWorker::RelayCommand::SWITCH_OFF);
                }
                break;
            case RelayTypes::RelayMode::AUTO:
                // implement rule node evaluation
                break;
            default:
                break;
            }
        }
    }
}

namespace Controller
{
    void update(unsigned long now)
    {
        static unsigned long last = 0;
        if (now - last < CONTROLLER_UPDATE_INTERVAL)
        {
            return;
        }
        if (!DataHub::getDataHub(dataHub))
        {
            Serial.printf("[%lus][ERROR] DataHub nicht lesbar\n", millis() / 1000);
            return;
        }

        monitorRelayStatus(now);
        enforceRelayState(now);
       // SensorManager::update(now);
        last = now;
    }
}

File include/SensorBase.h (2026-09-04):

#pragma once
#include <Arduino.h>
#include <ArduinoJson.h>
#include "NvsStorage.h"

constexpr const size_t SENSOR_UNIT_LEN = 16;
constexpr const size_t SENSOR_NAME_LEN = 32;
constexpr const float DEFAULT_SCALE = 1.0f;
constexpr const float DEFAULT_OFFSET = 0.0f;
constexpr const char CONFIG_KEY_SCALE[] = "scale";
constexpr const char CONFIG_KEY_OFFSET[] = "offset";
constexpr const char CONFIG_KEY_UNIT[] = "unit";
constexpr const char CONFIG_KEY_PRECISION[] = "precision";
constexpr const char CONFIG_KEY_SENSOR_NAME[] = "name";
constexpr const char CONFIG_KEY_SENSOR_TYPE[] = "type";
constexpr const char CONFIG_KEY_SENSOR_ID[] = "id";

/** @brief Abstract base class for all sensors */
class SensorBase
{
public:
    SensorBase(uint8_t id, const char *type);
    virtual ~SensorBase() = default;

    bool read(float &value, bool raw);

    virtual bool getCalibrationJson(char *buffer, size_t len) = 0;
    virtual bool getCalibrationValuesJson(char *buffer, size_t len) = 0;
    virtual bool calibrateSensorHardware(JsonObjectConst data) = 0;
    virtual void reset() = 0;
    virtual const char *getDefaultUnit() const = 0;
    virtual int getDefaultPrecision() const = 0;
    bool getName(char *buffer, size_t len);
    bool setName(const char *name, size_t len);
    bool getScale(float &scale) const;
    bool setScale(float scale);
    bool getOffset(float &offset) const;
    bool setOffset(float offset);
    bool getPrecision(int &precision) const;
    bool setPrecision(int precision);
    bool getUnit(char *buffer, size_t len) const;
    bool setUnit(const char *unit, size_t len);

    const char *getType() const;
    uint8_t getId() const;

protected:
    void nvsNamespace(char *buffer, size_t len) const;


private:
    uint8_t _id;
    const char *_type;
    virtual bool readRaw(float &buffer) = 0;
    void ensureDefaults();
};

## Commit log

2026-04-09 Add Fritzing schematic for MainUnit v1
    [TerraControl_MainUnit_V1.fzz]
2026-04-09 Initialize README with project overview and status
    Added project description, current status, and hardware details to README.
2026-04-10 Add unit tests, integration test docs, and heap monitoring
    - Add [env:native] with Google Test for unit tests
    - Add tests for normalizeMac and readLine with FakeStream
    - Add WiFiClient/Arduino stubs for native builds
    - Add integration test checklist (mDNS, MAC, switching, stability all passed)
    - Add periodic heap logging to loop() for stability monitoring
    - Minor hardware detail updates in CLAUDE.md and entscheidungen.md
    [main.cpp]
2026-04-12 Add SensorData struct and SensorType enum as sensor foundation
2026-04-13 Fix short circuit in schematic, add soil moisture sensor, remove debounce capacitor
    [TerraControl_MainUnit_V1.fzz]
2026-04-13 Revise wiring notes and update hardware list
    Updated component list and corrected wiring diagram note.
2026-04-14 Implements SensorData API for DataHub. Removes spurious xSemaphoreGive in wifiRelayToSerial.
2026-04-18 Refractor sensor architecture similar to wifiRelay Logic
2026-04-18 implement SensorManager as Caller Unit for all Sensors. Added reading logic for DHT22 and writing in DataHub
2026-04-20 Add calibration values and function
2026-04-24 Add Analog Sensor Example (Soil Moisture Sensor)
2026-04-24 Add DHT22 and Soil Moisture Sensor to roadmap
    Updated the roadmap to include DHT22 and Soil Moisture Sensor integration.
2026-05-12 feat: implement WiFiWorker AP mode, refactor HTTP stack, fix relay flickering
    New modules:
    - HttpClient: generic HTTP client with get() (full response) and sendGet()
    (status line only, stream left for caller); replaces direct TCP code
    - NetworkUtils: MAC/IP conversion utilities (normalizeMac, macBytesToChar,
    ipToChar); replaces HttpUtils
    - WiFiWorker: dedicated FreeRTOS task on Core 0; manages per-relay mailboxes
    (xQueueOverwrite), AP client events via std::atomic<bool>, and STA queue
    - Controller: switching logic orchestrator on Core 1; writes commands into
    WiFiWorker mailboxes; no direct network access
    DigestAuth refactoring:
    - First request now goes through HttpClient::sendGet()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
    [Controller.cpp, DataHub.cpp, DataHub.h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]
2026-05-14 refactor: replace WiFi event handlers with periodic polling, add GET_STATUS backoff
    Remove AP connect/disconnect event handlers in favour of periodic syncApClients()
    polling. Controller now polls GET_STATUS for all inUse relays regardless of online
    state. GET_STATUS_BACKOFF_MS (5s) prevents tight retry loops after failure. online=false
    set immediately on TCP error (-1); online=true exclusively from JsonParser. Remove
    setWifiRelayOfflineByIP(). Translate comments to English. Restore all relays to
    FORCED_OFF default.
    [Controller.cpp, DataHub.cpp, DataHub.h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]
2026-05-14 docs: update README with architecture overview, hardware split, and system image
    Add How It Works section with Soft-AP topology description and system overview
    image. Split hardware list into current and planned. Simplify roadmap descriptions.
    Expand Getting Started with Shelly connection step. Fix wifi_config.h.example
    (RELAY_USER, AP_WIFI_PW, remove unused NAME defines).
2026-05-16 docs: add OTA, flash encryption, power monitoring, and remote sensor protocol to CLAUDE.md
    Document Companion-App OTA architecture, NVS encryption path, INA219 self-power
    measurement, and finalized C3 remote sensor protocol (Digest Auth, MAC in realm,
    GET /sensors + /status format, Light Sleep, no calibration on C3).
2026-08-27 WIP: headless/GUI-worker CLAUDE.md rewrite, NVS-backed Logger and NvsStorage scaffolding
    Documents the headless (no display/SD) architecture decision and the
    RequestWorker/GuiWorker split in CLAUDE.md, cleans TFT/SD build flags
    from platformio.ini, and adds the first NvsStorage (RAII Session +
    mutex-guarded NVS access) and Logger modules for the sensor redesign.
    Untested — esp32dev builds, native test env is pre-existing broken
    (stale HttpUtils references) and will be fixed alongside the sensor
    and test-suite work.
2026-08-28 WIP: SensorBase (NVI) with NVS-backed output config, name and mutex fixes in NvsStorage
    Adds SensorBase abstract class: read()/isValid()/readRaw() NVI pattern,
    per-instance NVS namespace via id, universal scale/offset + name defaults
    seeded once in the constructor (ensureDefaults()), individual get/set for
    scale/offset/precision/unit/name (no bundled struct or JSON serialization
    at this layer - that's left to SensorManager). Type is a fixed,
    constructor-supplied label with no virtual dispatch involved.
    Also fixes remaining NvsStorage mutex issues (portMAX_DELAY without
    pdMS_TO_TICKS wrapping, readInt branch logic) found while wiring this up.
    Untested - no concrete sensor subclass exists ye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
    [SensorBase.h, main.cpp]
2026-08-28 Add public getId() to SensorBase
    Needed for switching rules to reference a stable sensor identity.
2026-08-29 WIP: DHT22Temperature as first SensorBase implementation, NVS write-failure logging
    Adds DHT22Temperature: readRaw()/reset() pattern, cached rate-limited
    DHT read (2s minimum interval), full reset (scale/offset/precision/unit)
    on first boot or explicit reset. Serves as the copy-paste template for
    further sensor types (DHT22Humidity, soil moisture, HX711).
    NvsStorage now logs write failures (namespace+key) via a single
    logWriteFailure() helper instead of duplicating the log call per
    write function. Read failures (key not found) are intentionally not
    logged there - that's an expected condition during first-boot default
    seeding, not an error; NvsStorage has no context to tell the two apart.
    R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
    [SensorBase.h]
2026-08-30 Add DHT22Humidity and SoilMoisture as SensorBase implementations
    Rename DHT22Temperature's lastTemperature to lastValue for naming
    consistency across sensor classes. SoilMoisture tracks calibrated
    validity via its own lastValid flag rather than re-deriving it from
    a stale raw-ADC range check on an already-converted percentage.
    The Omnissiah's algorithms flow through silicon as the Machine Spirit intended.
2026-09-02 Implement SensorManager: NVS-backed sensor registry, config JSON, heap-relaxation rule
    SensorManager now owns a std::vector<SensorBase*> covering local DHT22/SoilMoisture
    sensors, populated via new(std::nothrow) at init() with per-sensor failure logging
    and an aggregated success flag. Lookup is a linear getId() search rather than
    index-based, so removal (future remote sensors) never desyncs id from position.
    Adds SensorBase::getDefaultUnit()/getDefaultPrecision() so SensorManager can fall
    back to type-specific defaults when a config getter fails, and getSensorConfigJson/
    calibrateSensorConfig for bulk read/write of a sensor's config (name, unit, scale,
    offset, precision) with per-field part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
    [DataHub.h]
2026-09-04 Fix per-instance timer bug, StaticJsonDocument for output, first hardware test
    DHT22Temperature/Humidity/SoilMoisture readRaw() used a function-local
    static for the read-interval timer, shared across all instances of
    each class. With multiple DHT22 objects registered, only the first
    one per class ever got a fresh read - the rest stayed stuck at their
    initial invalid value regardless of wiring. Moved to a per-instance
    member (lastReadTime).
    Switch all sensor JSON output (calibration JSON, config JSON) from
    hand-rolled snprintf to StaticJsonDocument/serializeJson - closes a
    real escaping gap (an unescaped quote in a user-set sensor name broke
    the generated JSON) now that the display-driven fl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
    [Controller.cpp, SensorBase.h]
2026-09-04 WIP: RelayBase header sketch (NVI pattern, mirrors SensorBase)
    Header-only draft: id/type identity, switch/status request builders,
    name/password/failsafe-timeout as NVS-backed config. No .cpp yet -
    next step is the MAC-based persistent id registry discussed today
    (physical identity survives reboots, unlike the in-memory counter
    local sensors use), then the concrete Shelly implementation.
2026-09-06 Implement RelayBase (NVI) with NVS-backed config, add NvsStorage::clearNamespace
    RelayBase mirrors SensorBase's shape: id/type/relayIdx supplied by the
    caller at construction (no self-resolving registry lookup - that lives
    one level up, in the not-yet-written RelayManager), name/failsafeSeconds
    persisted per-relay via NVS. MAC and password deliberately excluded -
    neither is used by any of RelayBase's own methods (payload building/
    parsing), both belong to whichever component actually owns the network
    transport and the mac/relayIdx->id registry.
    remove() clears only this relay's own NVS namespace via the new
    NvsStorage::clearNamespace() (scoped to the currently-open namespace,
    unlike the exi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
2026-09-11 Add WiFiRelayManager, ShellyGen2Relay onboarding/recovery, RAM-cache SensorBase - UNTESTED
    - RelayBase: two-phase construction (recover()/onboard() replace parameter
    constructors so failure can be signaled), MAC/password now NVS-backed,
    std::atomic<bool> for cross-core found/outputOn
    - SensorBase: scale/offset/name/precision/unit cached in RAM with NVS
    write-through, mirroring RelayBase's pattern; read() no longer touches NVS
    - WiFiRelayManager: fixed-size RelaySlot[] registry (pointer+type per slot,
    index = persistent id), init/add/remove/find/markLost/getSwitchRequest/
    getStatusRequest/applyResponse/getFailsafeSeconds; registry persisted only
    on actual change, never held as a s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
2026-09-25 Checkpoint: finish ApDeviceRegistry, add SecureUtils/EntityBase/System - UNTESTED
    Reset point before refactoring ApDevice::applyResponse into a Template
    Method (ShellyDevice/C3Device subclasses), since device-status response
    shapes differ per manufacturer and a type-switch would defeat the
    inheritance-based design.
2026-10-18 WIP: factory functions for ApDevice/entities, NVS key prefixes, RAM-mirrored NVS values
    - EntityBase/RelayBase/ShellyGen2Relay/ApDevice: private ctor + static recover()/onboard()
    - RelayBase: explicit outputIdx ("output") instead of entity index
    - entities/sensors share one NVS namespace with prefixed keys (e<idx>_, s<id>_),
    key lengths enforced by static_assert
    - NVS values mirrored in RAM (secrets excluded), ApDeviceRegistry::Lock
    - ApDeviceRegistry does not compile yet (still calls old ApDevice ctors) - next step
2026-10-18 CLAUDE.md: invalid sensor value stops failsafe refresh instead of holding relay
    On an invalid sensor value the controller no longer keeps the relay in its last
    state indefinitely: it neither switches nor repeats SWITCH_ON, so a short glitch
    is bridged by the running failsafe, while a persistent failure lets the relay
    drop via toggle_after and notifies the user. Not implemented yet (switching-rule
    sprint).
2026-10-25 Registry on factory functions, no silent deletion, stable entity positions
    - ApDeviceRegistry: init()/create() use ApDevice::recover()/onboard();
    a slot is free only without object AND without NVS data (hasData());
    defect slots are logged and kept, never overwritten
    - create(): central NVS free-entry check (getFreeEntries()) before the
    duplicate check, so a rejected onboarding never deletes anything
    - ApDevice: destructor only frees memory, NVS removal moved to erase()
    (called by registry remove() and failed onboard() only)
    - ApDevice::load(): unloadable entity stays as nullptr at its position,
    following entities no longer shift onto the wrong index
    - ApDevice: static hasData(id),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
2026-10-25 Sensor validity hardening, review findings 14/15
    - ShellyGen2Relay::applyResponse(): check "output" with is<bool>(),
    never guess a state from a missing field
    - DHT22: all-zero telegram (humidity exactly 0.0, parasitic supply)
    reported invalid; temperature checks humidity of the same reading,
    validity kept per object
    - SoilMoisture: reject calibration with |dry - wet| < 500 or non-numeric
    values, and do not load such a pair from NVS (division by zero)
    - SensorBase: remember time of the last valid reading (getLastValid())
    - NvsStorage.h: remove anonymous-namespace declarations from header
    - RelayTypes.h removed (unused duplicate RelayMode)
    - CLAUDE.md: C3 protocol notes (validity + typ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
2026-10-26 SensorManager: fixed sensor IDs, no shift on failed allocation
    The ID counter (now nextSensorId) is incremented for every sensor
    position, also when the allocation fails. Before, a failed allocation
    made all following sensors take the previous sensor's ID and load its
    NVS settings (name, scale, offset, calibration). A failed sensor is
    simply not added to the vector; find() returns nullptr for its ID.
2026-10-29 RelayBase: persist RelayMode in NVS, failsafe minimum 30 s
2026-10-29 CLAUDE.md: switching model B worked out, docs synced with code
2026-11-01 CLAUDE.md: C3 /sensors format, API-first, ApDeviceSensor built
2026-11-03 README rewrite for current state, docs cleanup
    - README: status, design decisions, architecture, updated roadmap,
    hardware and getting started; Mermaid diagram replaces outdated image
    - integrationstests.md: marked as prototype results
    - cpp_reference_cheatsheet.md: DataHub examples removed
    - CLAUDE.md: rule "time as parameter"
2026-11-09 Fix findings from native test review
    - NvsStorage::writeString: empty string no longer reported as a failure
    (Preferences::putString returns strlen); verified by reading back
    - ApDevice: empty name is valid and stored; getName returns the stored
    value, getDefaultName provides the suggestion
    - ApDevice::load: missing/invalid entity count fails, slot counts as defective
    - ApDeviceRelayBase: stored failsafe below minimum falls back to the default;
    unknown stored mode loads as RelayMode::NOT_IN_LIST (RAM-only, not settable)
    - NetworkUtils::macCharToBytes: only exactly 12 hex digits are accepted
    - ApDeviceSensor::setPrecision: correct log message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
2026-11-09 Native unit tests for devices, entities and registry
    - Preferences/nvs_flash stand-ins on an in-memory NVS, so the real
    NvsStorage.cpp is tested; FreeRTOS stand-in counts double-taken mutexes
    - Tests for ApDevice onboarding/recover, setters (NVS before RAM),
    ShellyGen2Relay, ApDeviceSensor, ApDevice::applyResponse, ApDeviceRegistry
    - test_read_line re-enabled against HttpClient
    - env:native builds the listed src/ files (test_build_src)
2026-11-09 CLAUDE.md: open points for the C3 sensor node rework
